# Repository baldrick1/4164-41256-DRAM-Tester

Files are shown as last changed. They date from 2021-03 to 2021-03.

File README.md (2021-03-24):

Arduino based 4164 / 41256 DRAM tester

This project hosts the source material to build a 4164 / 41256 DRAM chip tester based on an Arduino Nano.

Instructions: Insert chip to be tested into the ZIF socket, select 4164 or 41256 via toggle switch, power up the Arduino (either through the USB port or optional power port for standalone operation) and press the "START" button.

The green LED will blink thoughout the test.  A 4164 takes approximately 80 seconds to test, a 41256 will take longer.

If you connect the USB cable to your host computer and use the Arduino Serial Monitor, the tester will return a good / bad result and where the bad result occurred.

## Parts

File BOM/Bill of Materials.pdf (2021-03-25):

Part | Part Number | Description | Value | Suplier
A1 | Arduino Nano v3.0 Arduino Nano v3.0 | - | Arduino.cc
ZIF Socket1 216-3340-00-0602J Zif Socket 16 pin DIP - | Digikey
J1 | PJ-002A | Power Jack | 2mm X 5.5mm | Digikey
LED1 | MT4118-HR-A | Red LED | 5mm round | Digikey
LED2 | MT2118-G-A | Green LED | 5mm round | Digikey
R1 | 470QBK-ND | Resistor | 470 ohm | Digikey
R2 | 470QBK-ND | Resistor | 470 ohm | Digikey
R3 | 1.0KQBK-ND | Resistor | 1.0k ohm | Digikey
SW1 | PVA1EEH1 | Pushbutton | Momentary DPST | Mouser
SW1CAP | 611-PVBK | Cap for PB | Black | Mouser

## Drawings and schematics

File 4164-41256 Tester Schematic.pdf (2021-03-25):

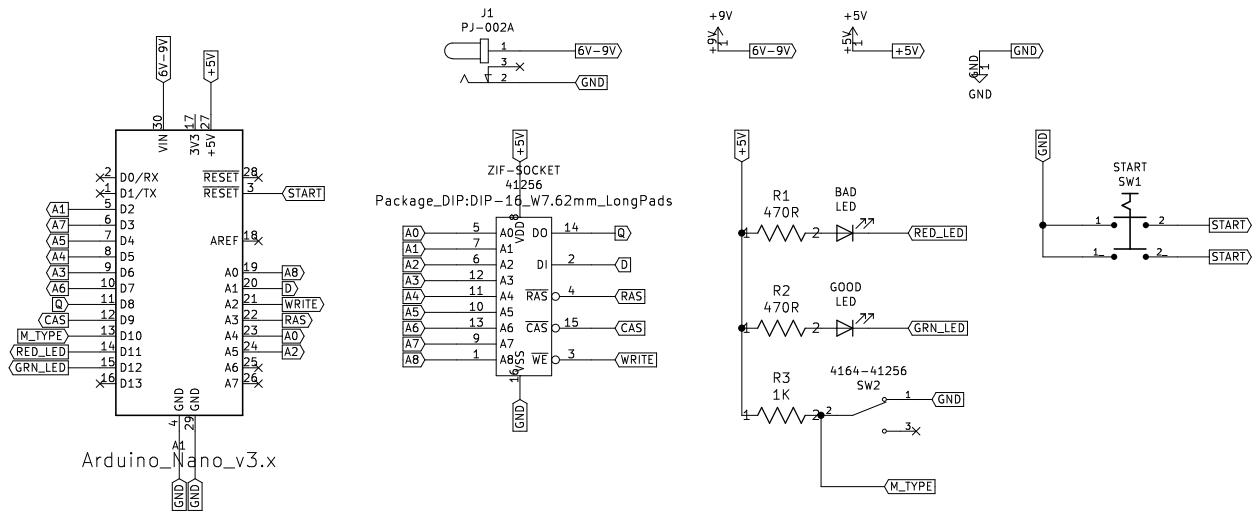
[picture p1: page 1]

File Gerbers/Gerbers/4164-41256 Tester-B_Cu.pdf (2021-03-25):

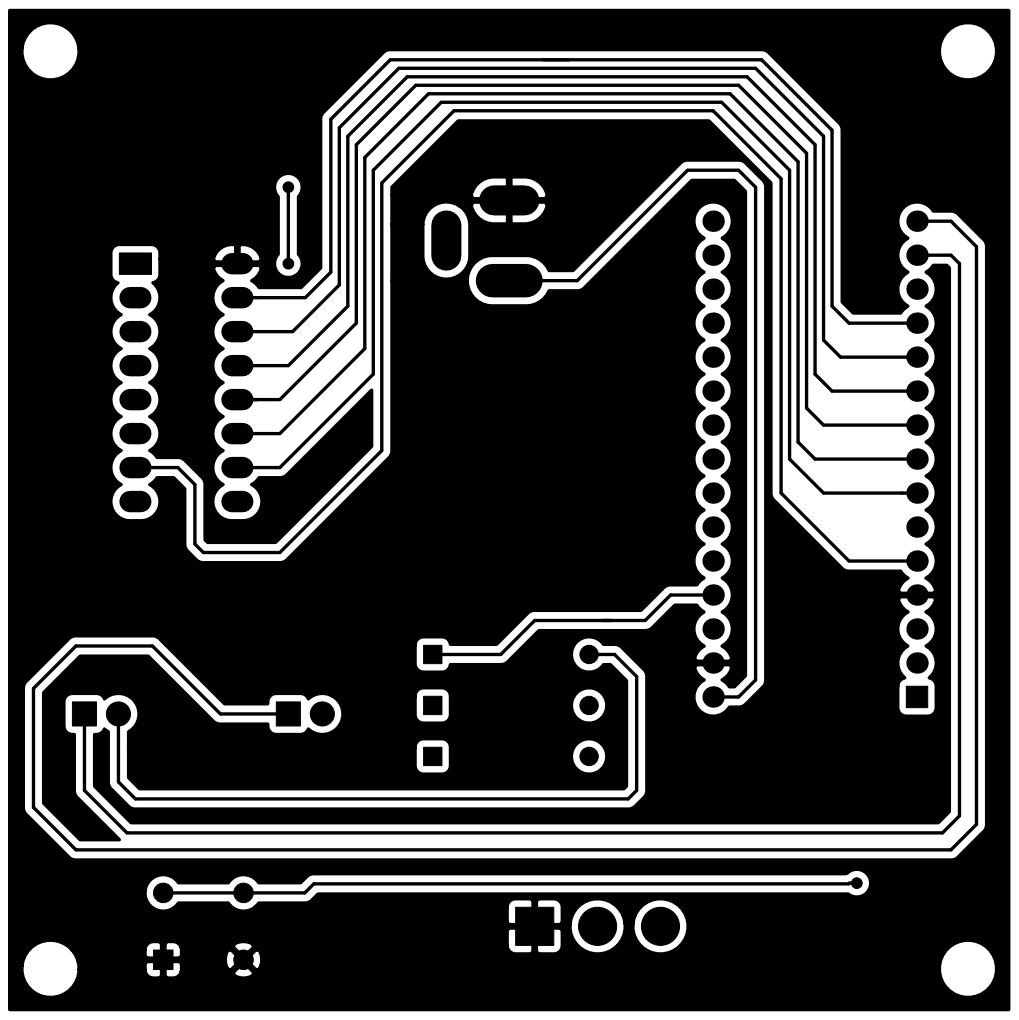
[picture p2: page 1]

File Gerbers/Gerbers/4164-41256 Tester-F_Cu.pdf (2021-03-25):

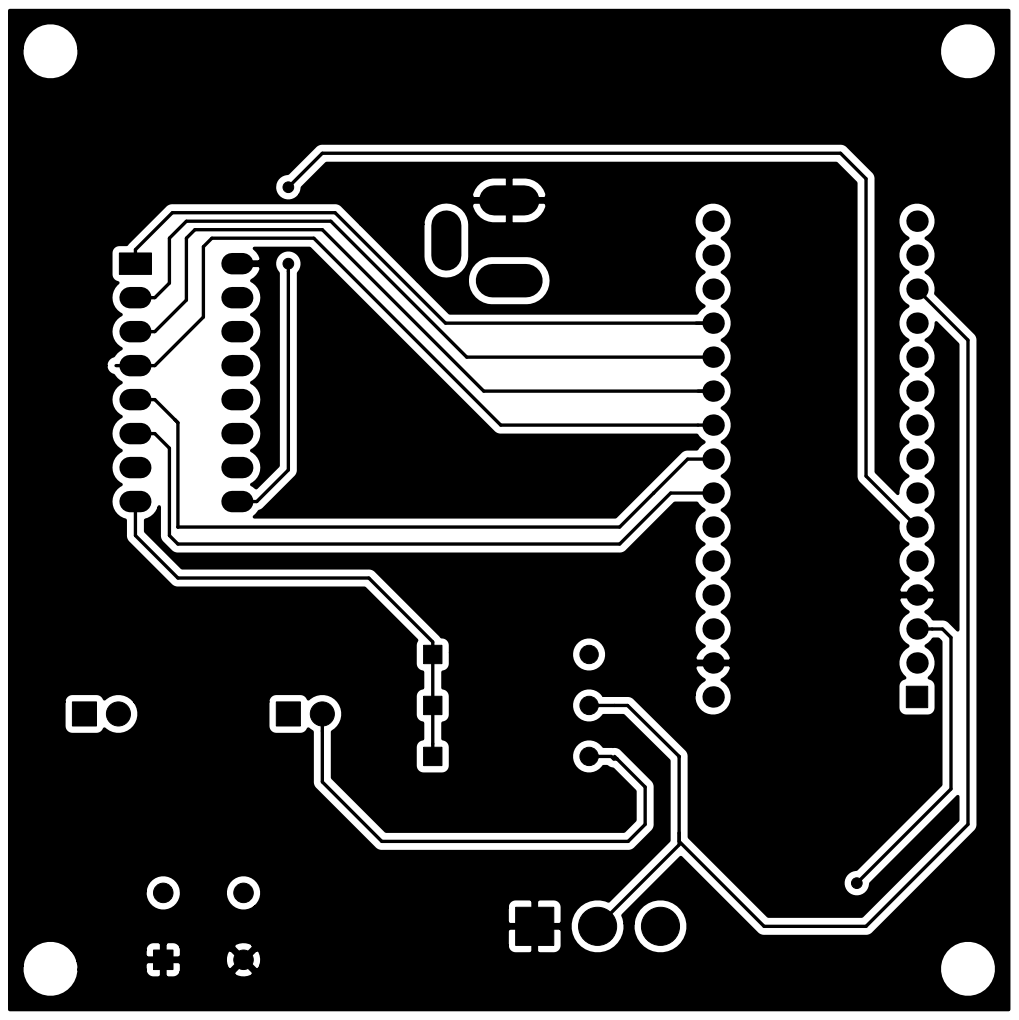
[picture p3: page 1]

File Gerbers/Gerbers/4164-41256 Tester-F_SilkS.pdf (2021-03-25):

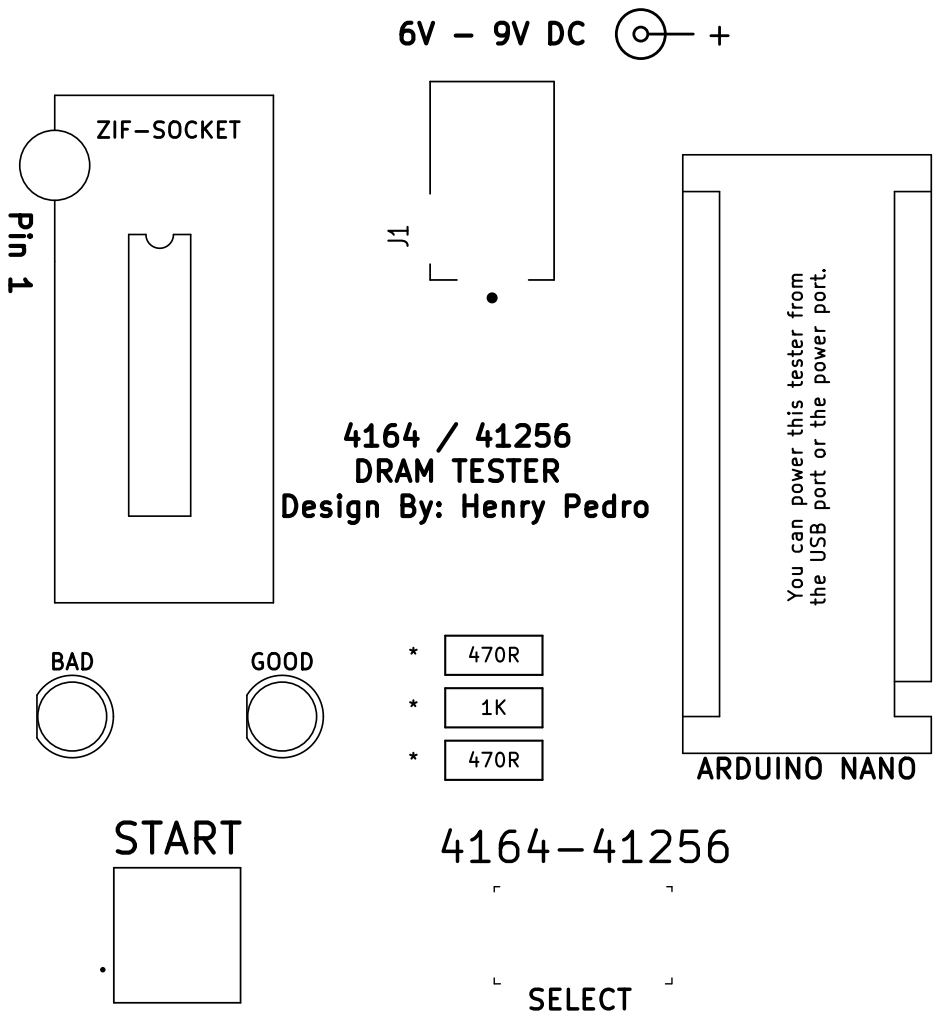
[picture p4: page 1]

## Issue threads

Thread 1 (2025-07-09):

strange behavior

maikelsz, 2025-07-09:
Hi, I've made the circuit and tested the corrected code from 2020.10.29. I'm running it on an Arduino Uno R4.
But something different is happening.
When testing both 4164 and 41256, the green LED blinks rapidly and the red one stays off. Then, when the test seems to end, both remain lit steadily, and the terminal doesn't show the final test result either.
I tested 15 MN41256 and 3 MB8264, all do the same.
I don't have a chip that I'm 100% sure is working; that's why I built the tester. But with a small group of MB81256 (from Mitsubishi, they seem to be 100% compatible with 41256), it barely starts. The green LED flashes briefly once, then immediately ends with an error, and the red LED stays lit steadily. On the terminal, the address is always one of the first ones.
Any thoughts on this behavior?

baldrick1, 2025-07-13:
I have not tested this with an Arduino Uno, just a Nano, so there may be a compatibility issue at play.
Nanos based off of the ATmega328P 5V 16MHz CH340G Chip Microcontroller are dirt cheap and you could probably get one in a day or two from Amazon.
The board design is tested and works with the above Nano or Nano clone board.
There is one known issue with 41256/4164 selection - because the two chips are identical save for one extra address pin, if you put in a 4164 with the switch selected for 41256, it will run the test attempting to activate the extra address pin, and since there isn't one, the test will take 4 times as long and will still pass.

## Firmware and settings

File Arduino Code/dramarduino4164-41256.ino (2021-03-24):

/*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
**  
**  Derived from work created by:
**  _
** |_|___ ___
** | |_ -|_ -|
** |_|___|___|
**  iss(c)2020
**
**  Based on a project hosted at: https://forum.defence-force.org/viewtopic.php?f=9&t=1699
**
*/

#include <SoftwareSerial.h>

#define DI          15  // PC1  4164/41256 pin 2
#define DO           8  // PB0  4164/41256 pin 14
#define CAS          9  // PB1  4164/41256 pin 15
#define RAS         17  // PC3  4164/41256 pin 4
#define WE          16  // PC2  4164/41256 pin 3

#define XA0         18  // PC4  4164/41256 pin 5
#define XA1          2  // PD2  4164/41256 pin 7
#define XA2         19  // PC5  4164/41256 pin 6
#define XA3          6  // PD6  4164/41256 pin 12
#define XA4          5  // PD5  4164/41256 pin 11
#define XA5          4  // PD4  4164/41256 pin 10
#define XA6          7  // PD7  4164/41256 pin 13
#define XA7          3  // PD3  4164/41256 pin 10
#define XA8         14  // PC0  4164 N/C / 41256 pin 1

#define M_TYPE      10  // PB2
#define R_LED       11  // PB3
#define G_LED       12  // PB4

#define RXD          0  // PD0
#define TXD          1  // PD1

#define BUS_SIZE     9

/* ================================================================== */
volatile int bus_size;

//SoftwareSerial USB(RXD, TXD);

const unsigned int a_bus[BUS_SIZE] = {
  XA0, XA1, XA2, XA3, XA4, XA5, XA6, XA7, XA8
};

void setBus(unsigned int a) {
  int i;
  for (i = 0; i < BUS_SIZE; i++) {
    digitalWrite(a_bus[i], a & 1);
    a /= 2;
  }
}

void writeAddress(unsigned int r, unsigned int c, int v) {
  /* row */
  setBus(r);
  digitalWrite(RAS, LOW);

  /* rw */
  digitalWrite(WE, LOW);

  /* val */
  digitalWrite(DI, (v & 1) ? HIGH : LOW);

  /* col */
  setBus(c);
  digitalWrite(CAS, LOW);

  digitalWrite(WE, HIGH);
  digitalWrite(CAS, HIGH);
  digitalWrite(RAS, HIGH);
}

int readAddress(unsigned int r, unsigned int c) {
  int ret = 0;

  /* row */
  setBus(r);
  digitalWrite(RAS, LOW);

  /* col */
  setBus(c);
  digitalWrite(CAS, LOW);

  /* get current value */
  ret = digitalRead(DO);

  digitalWrite(CAS, HIGH);
  digitalWrite(RAS, HIGH);

  return ret;
}

void error(int r, int c)
{
  unsigned long a = ((unsigned long)c << bus_size) + r;
  digitalWrite(R_LED, LOW);
  digitalWrite(G_LED, HIGH);
  interrupts();
  Serial.println();
  Serial.print("CHIP FAILED TEST $");
  Serial.println(a, HEX);
  Serial.flush();
  while (1)
    ;
}

void ok(void)
{
  digitalWrite(R_LED, HIGH);
  digitalWrite(G_LED, LOW);
  interrupts();
  Serial.println();
  Serial.println("CHIP TESTED OK!");
  Serial.flush();
  while (1)
    ;
}

void blink(void)
{
  digitalWrite(G_LED, LOW);
  digitalWrite(R_LED, LOW);
  delay(1000);
  digitalWrite(R_LED, HIGH);
  digitalWrite(G_LED, HIGH);
}

void green(int v) {
  digitalWrite(G_LED, v);
}

void fill(int v) {
  int r, c, g = 0;
  v &= 1;
  for (c = 0; c < (1 << bus_size); c++) {
    green(g ? HIGH : LOW);
    for (r = 0; r < (1 << bus_size); r++) {
      writeAddress(r, c, v);
      if (v != readAddress(r, c))
        error(r, c);
    }
    g ^= 1;
  }
  blink();
}

void fillx(int v) {
  int r, c, g = 0;
  v &= 1;
  for (c = 0; c < (1 << bus_size); c++) {
    green(g ? HIGH : LOW);
    for (r = 0; r < (1 << bus_size); r++) {
      writeAddress(r, c, v);
      if (v != readAddress(r, c))
        error(r, c);
      v ^= 1;
    }
    g ^= 1;
  }
  blink();
}

void setup() {
  int i;

  Serial.begin(9600);
  while (!Serial)
    ; /* wait */

  Serial.println();
  Serial.print("4164 - 41256 DRAM TESTER");

  Serial.println();
  Serial.print("Licensed under GPL v3.0");
  Serial.println();
  
  for (i = 0; i < BUS_SIZE; i++)
    pinMode(a_bus[i], OUTPUT);

  pinMode(CAS, OUTPUT);
  pinMode(RAS, OUTPUT);
  pinMode(WE, OUTPUT);
  pinMode(DI, OUTPUT);

  pinMode(R_LED, OUTPUT);
  pinMode(G_LED, OUTPUT);

  pinMode(M_TYPE, INPUT);
  pinMode(DO, INPUT);

  digitalWrite(WE, HIGH);
  digitalWrite(RAS, HIGH);
  digitalWrite(CAS, HIGH);

  digitalWrite(R_LED, HIGH);
  digitalWrite(G_LED, HIGH);

  if (digitalRead(M_TYPE)) {
    /* jumper not set - 41256 */
    bus_size = BUS_SIZE;
    Serial.print("CHIP IS 256K x 1");
  } else {
    /* jumper set - 4164 */
    bus_size = BUS_SIZE - 1;
    Serial.print("CHIP IS 64K x 1");
  }
  Serial.flush();

  digitalWrite(R_LED, LOW);
  digitalWrite(G_LED, LOW);

  noInterrupts();
  for (i = 0; i < (1 << BUS_SIZE); i++) {
    digitalWrite(RAS, LOW);
    digitalWrite(RAS, HIGH);
  }
  digitalWrite(R_LED, HIGH);
  digitalWrite(G_LED, HIGH);
}

void loop() {
  interrupts(); Serial.print("."); Serial.flush(); noInterrupts(); fillx(0);
  interrupts(); Serial.print("."); Serial.flush(); noInterrupts(); fillx(1);
  interrupts(); Serial.print("."); Serial.flush(); noInterrupts(); fill(0);
  interrupts(); Serial.print("."); Serial.flush(); noInterrupts(); fill(1);
  ok();
}

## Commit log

2021-03-24 Add files via upload
    Added Arduino sketch
2021-03-25 Add files via upload
    Schematics for 4164 - 41256 DRAM tester
2021-03-25 Create newfile.md
    PCB Gerbers and drill files here.
2021-03-25 Add files via upload
    PCB Gerbers and drill files here
    [4164-41256 Tester-B_CrtYd.gbr, 4164-41256 Tester-B_Cu.gbr, 4164-41256 Tester-B_Mask.gbr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]
2021-03-25 Add files via upload
    Arduino code for 4164 - 41256 DRAM tester. Uses Arduino Nano v3.x
2021-03-25 Add files via upload
    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
2021-03-25 Add files via upload
    Bill of materials here.
    [Bill of Materials.csv]

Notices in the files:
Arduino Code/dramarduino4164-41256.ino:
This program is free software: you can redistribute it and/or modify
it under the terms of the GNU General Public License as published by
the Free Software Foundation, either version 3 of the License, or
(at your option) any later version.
